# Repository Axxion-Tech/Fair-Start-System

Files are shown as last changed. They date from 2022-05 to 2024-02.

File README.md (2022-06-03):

# Fair Start System

An Arduino-controlled, servo-operated starting box for drone racing.

## Installing

Download and extract the zip file to your chosen directory. Double-click `Fair Start System.pyw` (found in the root directory of the project) to open the application and get started!

## Requirements to Run Application

- [python 3](https://www.python.org/downloads/)
- [pyserial](https://pyserial.readthedocs.io/en/latest/) (`pip install pyserial`)
- [playsound 1.2.2](https://pypi.org/project/playsound/1.2.2/) (`pip install playsound==1.2.2`)

## Requirements to Flash Arduino

- [VarSpeedServo](https://github.com/netlabtoolkit/VarSpeedServo)
- [FastLED](https://github.com/FastLED/FastLED)

##### Designed and developed by Axxion Technologies

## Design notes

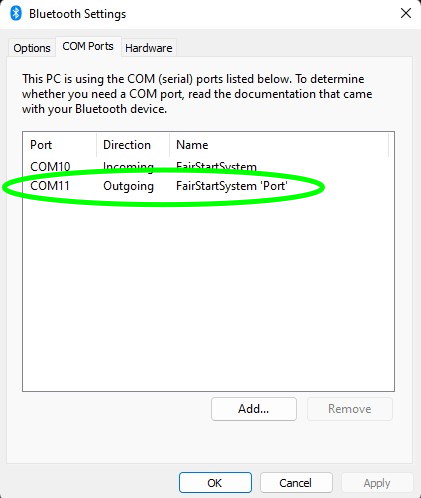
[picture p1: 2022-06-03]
assets/images/windows_3.jpg

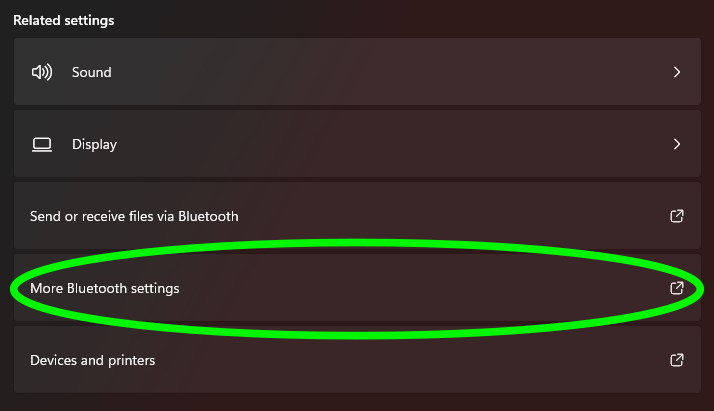
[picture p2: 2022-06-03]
assets/images/windows_2.jpg

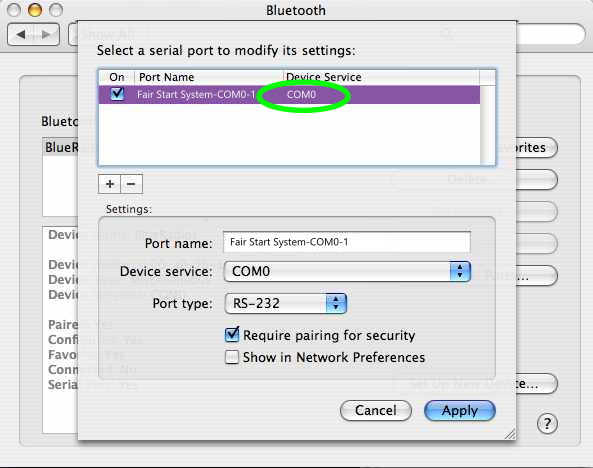
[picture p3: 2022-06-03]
assets/images/mac_2.jpg

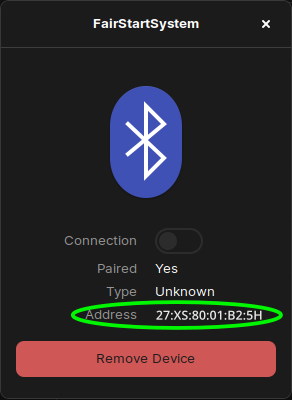
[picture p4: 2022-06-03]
assets/images/linux_1.jpg

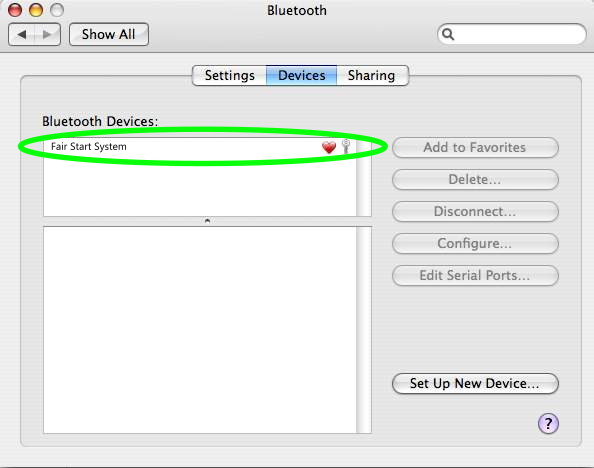
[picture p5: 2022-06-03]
assets/images/mac_1.jpg

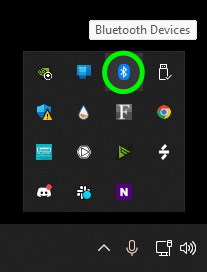
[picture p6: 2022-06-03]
assets/images/windows_1.jpg

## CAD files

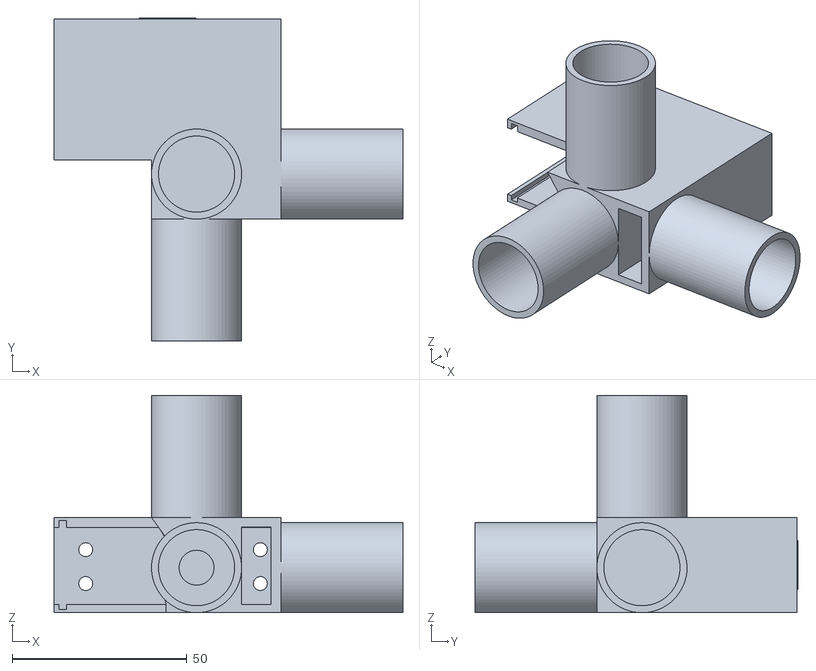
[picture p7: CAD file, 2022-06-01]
assets/stl/Servo Box Right.stl
100.0 x 92.7 x 62.3

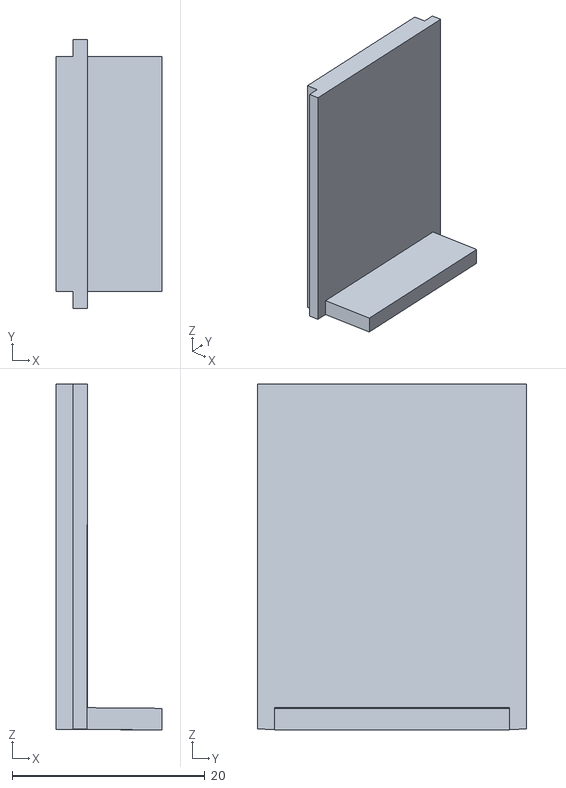
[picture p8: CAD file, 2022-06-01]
assets/stl/Left Servo Cover.stl
11.0 x 27.9 x 35.9

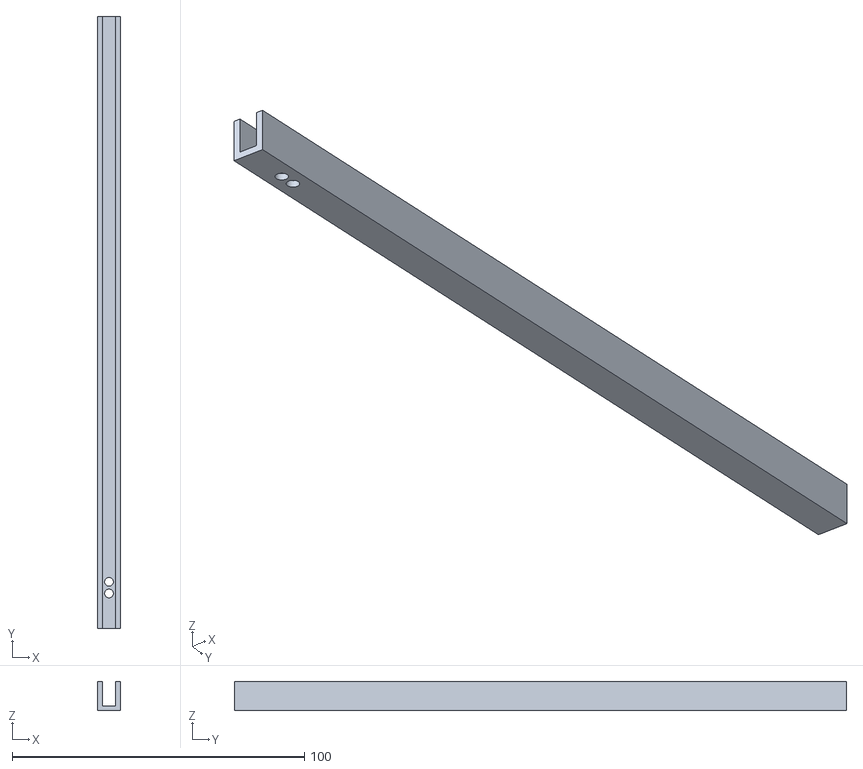
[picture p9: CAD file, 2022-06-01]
assets/stl/Panel Side Rail.stl
8.00 x 209.5 x 10.0

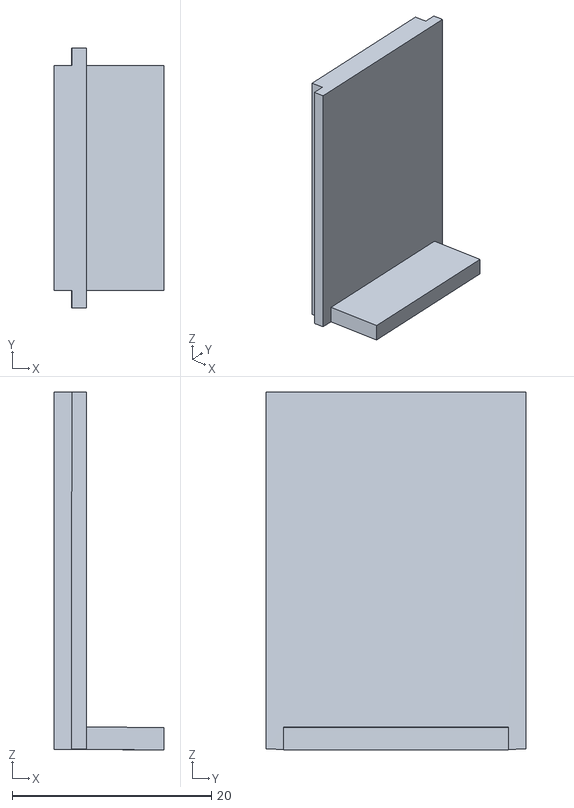
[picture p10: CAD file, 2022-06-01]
assets/stl/Right Servo Cover.stl
11.0 x 26.0 x 35.9

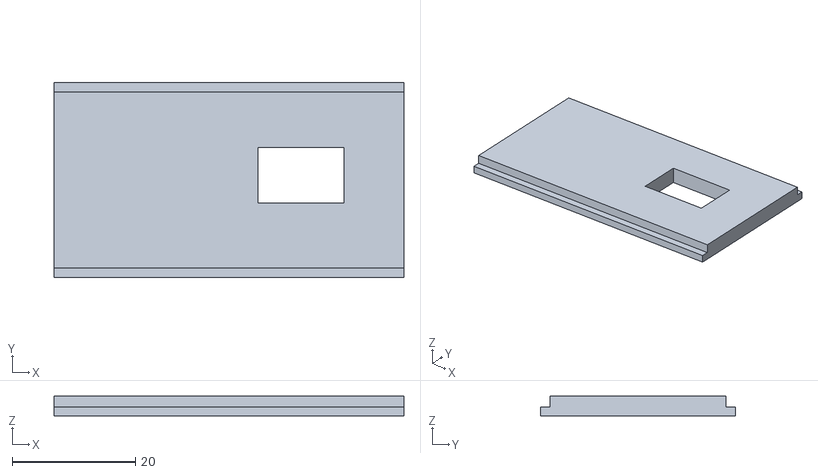
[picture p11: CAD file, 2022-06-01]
assets/stl/Left Arduino Cover.stl
56.9 x 31.7 x 3.24

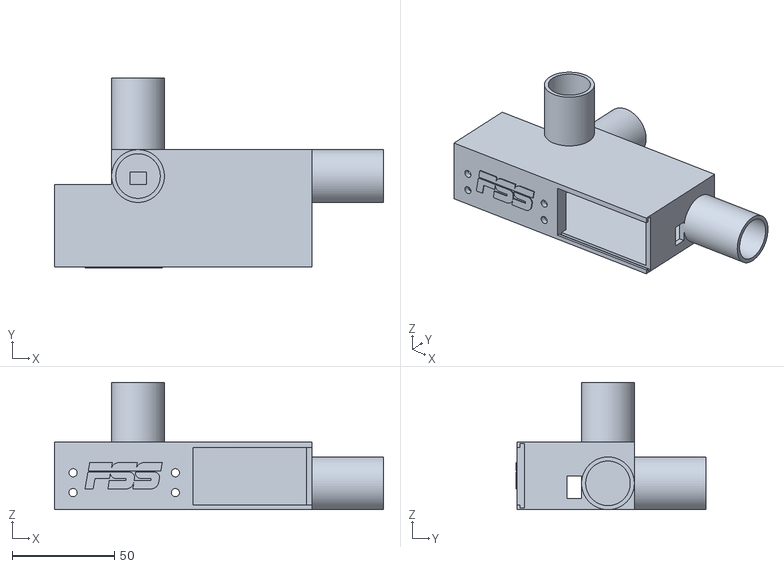
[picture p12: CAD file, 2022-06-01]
assets/stl/Servo and Arduino Box Left.stl
160.9 x 92.8 x 62.3

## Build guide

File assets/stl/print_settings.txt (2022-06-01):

--------------------------------------------
Servo and Arduino Box Left / Servo Box Right (PLA+)

### Slicer Settings ###
Layer Height: 0.3
Line Width: 0.45
Wall Line Count: 3
Infill Density: 65%
Infill Pattern: Cubic
Print Speed: 70 mm/s
Enable Retraction: Yes
Generate Support: Yes
Support Structure: Tree
Support Placement: Everywhere

### Notes ###
Some of the smaller holes and overhangs shouldn't need supports. Use good judgement and place support blockers
where you think your printer should be able to handle it. Use the right temperatures and fan speed for the 
material you choose to print in. Finally, pay close attention to the support structure and density. It can 
be a challenge ripping out the supports after printing if you allow too much material.

----------------------------------------------
Right Servo Cover / Left Arduino Cover / Left Servo Cover / Panel Side Rails (PLA+)

### Slicer Settings ###
Layer Height: 0.2
Line Width: 0.45
Wall Line Count: 3
Infill Density: 65%
Infill Pattern: Cubic
Print Speed: 60 mm/s
Enable Retraction: Yes
Generate Support: No

### Notes ###
Print the L-shaped covers standing up on the short side to avoid supports. Two side rails are required, but they are the exact same model for the left and right, so just duplicate it. Depending on printer calibration, the covers may need to be scaled or modified to fit the corresponding slots perfectly.

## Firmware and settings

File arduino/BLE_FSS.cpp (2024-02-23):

#include <FastLED.h>
#include <VarSpeedServo.h>

#define LED_PIN 8
#define NUM_LEDS 25

VarSpeedServo l;
VarSpeedServo r;
int lStartPosition = 180; // Left servo start position (angle)
int lEndPosition = 90; // Left servo end position (angle)
int rStartPosition = 0; // Right servo start position (angle)
int rEndPosition = 90; // Right servo end position (angle)
uint8_t gHue = 0; // Starting hue value

CRGB leds[NUM_LEDS]; // Setup LEDs

void rainbow_wave(uint8_t thisSpeed, uint8_t deltaHue) {      // The fill_rainbow call doesn't support brightness levels.
  uint8_t thisHue = beatsin8(thisSpeed,0,255);                // A simple rainbow wave.
  fill_rainbow(leds, NUM_LEDS, thisHue, deltaHue);            // Use FastLED's fill_rainbow routine.
}
void setup()
{
  FastLED.addLeds<WS2812, LED_PIN, GRB>(leds, NUM_LEDS); // Arrange LED Strip
  fill_solid( leds, NUM_LEDS, CRGB(255, 0, 0) ); // Set all LEDs to red
  FastLED.show();
  l.attach(3); // Left servo is connected to pin 10 of arduino
  l.write(lStartPosition); // Set left inital servo position to 90
  r.attach(2); // Right servo is connected to pin 10 of arduino
  r.write(rStartPosition); // Set left inital servo position to 180
  Serial.begin(9600); // Begin serial at 9600 baud rate
}
void loop()
{
  if(Serial.available()>0) // If bluetooth module is transmitting data
  {
    int command = Serial.read(); // Store the command in a variable
    Serial.println("Received command: " + String(command)); // Print command out
    if (command==48) { // When the command is utf-8 "0"
      Serial.println("Resetting");
      r.write(rStartPosition, 20);
      l.write(lStartPosition, 20); // Move servos closed
      fill_solid( leds, NUM_LEDS, CRGB(255, 0, 0) ); // Turn all LEDs red
      FastLED.show();
      delay(100);
    }
    else if (command==49){ // When the command is utf-8 "1"
      Serial.println("Firing");
      l.write(lEndPosition); // Move servos open
      r.write(rEndPosition);
      fill_solid( leds, NUM_LEDS, CRGB(0, 255, 0) ); // Turn all LED's green
      FastLED.show();
      delay(100);
    }
    else if(command==50){ // When the command is utf-8 "2"
      Serial.println("Countdown");
      fill_solid( leds, NUM_LEDS, CRGB(0, 0, 0) ); // Turn off all LEDs
      FastLED.show();
      delay(1);
      leds[0] = CRGB(255, 140, 0); // Show yellow LEDs in a sequence of five at a time
      leds[1] = CRGB(255, 140, 0);
      leds[2] = CRGB(255, 140, 0);
      leds[3] = CRGB(255, 140, 0);
      leds[4] = CRGB(255, 140, 0);
      leds[20] = CRGB(255, 140, 0);
      leds[21] = CRGB(255, 140, 0);
      leds[22] = CRGB(255, 140, 0);
      leds[23] = CRGB(255, 140, 0);
      leds[24] = CRGB(255, 140, 0);
      FastLED.show();
      delay(1000);
      leds[5] = CRGB(255, 140, 0);
      leds[6] = CRGB(255, 140, 0);
      leds[7] = CRGB(255, 140, 0);
      leds[8] = CRGB(255, 140, 0);
      leds[9] = CRGB(255, 140, 0);
      leds[15] = CRGB(255, 140, 0);
      leds[16] = CRGB(255, 140, 0);
      leds[17] = CRGB(255, 140, 0);
      leds[18] = CRGB(255, 140, 0);
      leds[19] = CRGB(255, 140, 0);
      FastLED.show();
      delay(1000);
      leds[10] = CRGB(255, 140, 0);
      leds[11] = CRGB(255, 140, 0);
      leds[12] = CRGB(255, 140, 0);
      leds[13] = CRGB(255, 140, 0);
      leds[14] = CRGB(255, 140, 0);
      FastLED.show();
    }
    else if (command==51){ // When the command is utf-8 "3"
      Serial.println("Red LEDs");
      fill_solid( leds, NUM_LEDS, CRGB(255, 0, 0) ); // Set all LEDs to red
      FastLED.show();
      delay(100);
    }
    else if (command==52){ // When the command is utf-8 "4"
      Serial.println("Rainbow Wave LEDs");
      fill_rainbow( leds, NUM_LEDS, gHue, 7);
      FastLED.show();
      delay(100);
    }
  }
}

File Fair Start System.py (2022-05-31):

import serial
import sys
import os
from os import startfile
import time
import random
import tkinter as tk
from tkinter import *
from tkinter import messagebox
from threading import Thread
from playsound import playsound

root= tk.Tk()
root.title("Fair Start System")
root.iconbitmap(os.path.dirname(__file__) + '/assets/images/short_logo.ico')

top = Frame(root)
top.pack(side=TOP, fill=BOTH, expand=True)

bottom = Frame(root)
bottom.pack(side=BOTTOM, fill=BOTH, expand=True)

header = tk.Canvas(root, width = 600, height = 80, relief="raised", background="#C80000")
header.pack(in_=top)

body = tk.Canvas(root, width = 400, height = 200, relief="raised")
body.pack()

main_logo = PhotoImage(file = os.path.dirname(__file__) + '/assets/images/full_logo_small.png')
header.create_image(300, 40, image = main_logo)

input_label = tk.Label(root, text='Enter Bluetooth Port:')
input_label.config(font=('helvetica', 14))
body.create_window(200, 100, window=input_label)

input = tk.Entry(root, width=30, justify=CENTER) 
body.create_window(200, 145, window=input)

notification = tk.Label(root)
notification.pack(pady=50)

wait_sound = os.path.dirname(__file__) + '/assets/sound/wait.mp3'
start_sound = os.path.dirname(__file__) + '/assets/sound/start.mp3'

def startRace():
	try:
		button1['state'] = "disable" # Disable start button
		button1['bg'] = "grey"
		port=input.get() # Read the port entered in the command line. The format will vary between Windows/Mac/Linux
		notification.config(text = "Searching for FairStartSystem on {}...".format(port))
		bluetooth=serial.Serial(port, 15200) # Initiate bluetooth connection with 15200 baud rate
		notification.config(text = "Connected")

		random_num = random.random() * 3.5
		notification.config(text = "This countdown delay: {} seconds".format(round(random_num, 2))) # Show the current randomized countdown
		bluetooth.flushInput() # Pulse check bluetooth

		bluetooth.write(bytes("2",'utf-8')) # Send the arduino a command to show countdown LEDs
		playsound(wait_sound) # Play the initial three start tones
		time.sleep(random_num) # Wait a short random amount of time (keep 'em guessing)

		bluetooth.write(bytes("1",'utf-8')) # Send the arduino a command to open the gate
		notification.config(text = "RACE START")
		time.sleep(0.2) # Wait a brief moment (to compensate for servo movement)
		playsound(start_sound) # Play the start sound

		time.sleep(10)   # Delay for 10 seconds
		notification.config(text = "Resetting...")
		bluetooth.write(bytes("0",'utf-8')) # Send the arduino a command to close the gate
		notification.config(text = "Done.")
		time.sleep(5)
		button1['bg'] = "green" # Restore start button
		button1['state'] = 'normal'
		return
	except serial.SerialException:
		notification.config(text="")
		if not port:
			tk.messagebox.showerror('Input Error', 'Please enter a port in the input.')
		else:
			tk.messagebox.showerror('Bluetooth Error', 'Could not find device on port {}'.format(port))
		button1['bg'] = "green"
		button1['state'] = 'normal'
	except Exception as ex:
		ex_value = sys.exc_info()
		notification.config(text="")
		tk.messagebox.showerror('Error', ex_value)
		button1['bg'] = "green"
		button1['state'] = 'normal'

def startRaceThreaded(): # Real-time notification updates requires threading
	global t
	t = Thread(target=startRace)
	t.start()

def openHelp(): # Show help page
    startfile(os.path.dirname(__file__) + '/help.html')

def openAbout(): # Show about page
    startfile(os.path.dirname(__file__) + '/about.html')

help_link = tk.Button(text='Help', command=openHelp, fg='blue', font=('helvetica', 9),  highlightthickness = 0, bd = 0, padx=100, pady=30)
help_link.pack(in_ = bottom, side = LEFT)

about_link = tk.Button(text='About', command=openAbout, fg='blue', font=('helvetica', 9),  highlightthickness = 0, bd = 0, padx=100, pady=30)
about_link.pack(in_ = bottom, side = RIGHT)

button1 = tk.Button(text='Start Race', command=startRaceThreaded, bg='green', fg='white', font=('helvetica', 12, 'bold'), padx=10, pady=5)
body.create_window(200, 200, window=button1)

root.mainloop()

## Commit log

2022-05-29 add LED functionality to Arduino code
2022-05-29 add LED functionality to python script
2022-05-30 change servo library to VarSpeedServo
2022-05-31 add assets and stl, start about and help page
    [Panel Side Rails.stl, Servo Box Arduino Cover.stl, Servo Box Left Cover.stl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]
2022-05-31 fill out readme
    [Panel Side Rails.stl, Servo Box Arduino Cover.stl, Servo Box Left Cover.stl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]
2022-06-01 add to stl folder
    [Left Arduino Cover.stl, Left Servo Cover.stl, Panel Side Rail.stl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]
